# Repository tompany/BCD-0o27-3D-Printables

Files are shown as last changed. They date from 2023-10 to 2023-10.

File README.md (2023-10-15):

# BCD-0o27-3D-Printables

3D printable enclosure for the BCD-0o27-3 created by Florian Schuetz. The original project can be found here: https://gitlab.com/fschuetz/bcd-0o27

This is a 3D printable vintage Nintendo like casing for the BCD-0o27 including a print and assemble guide. Made this for two colleagues who visited the BalCCon2k23.

## What is in this repository
* The STL printable files are in the ["STL files"](./STL%20files) directory
* The **editable** original Autodesk Fusion 360 design is in the ["F3D files"](./F3D%20files) directory
* A print and assembly manual can be found here: [3D print and Assembly Manual](/3D%20print%20and%20Assembly%20Manual%20.md)

The design in the above-mentioned F3D file was created by Tom van Thiel, with the exception of the printed circuit board and the parts placed on it. That was copied from the original [BCD-0o27 repo](https://gitlab.com/fschuetz/bcd-0o27/-/tree/main/hardware/BCD-0o27?ref_type=heads) of [Florian Schuetz](https://gitlab.com/fschuetz).

If you have any question about the design, please send me a message on Discord: 703155474991939584 (display name: "Tompany")
P.s.: You can lookup Discord ID's here: [discord.id](https://discord.id/)

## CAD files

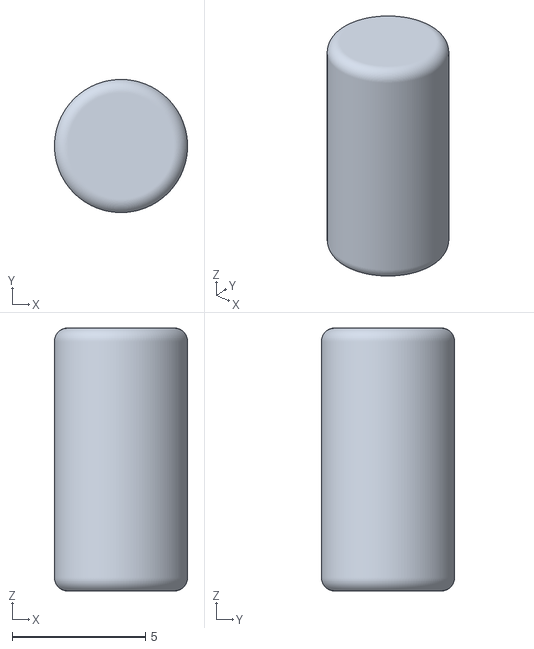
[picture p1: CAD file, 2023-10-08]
STL files/ANYCOLUR___bmRedButtonRodY.stl
5.00 x 5.00 x 9.88

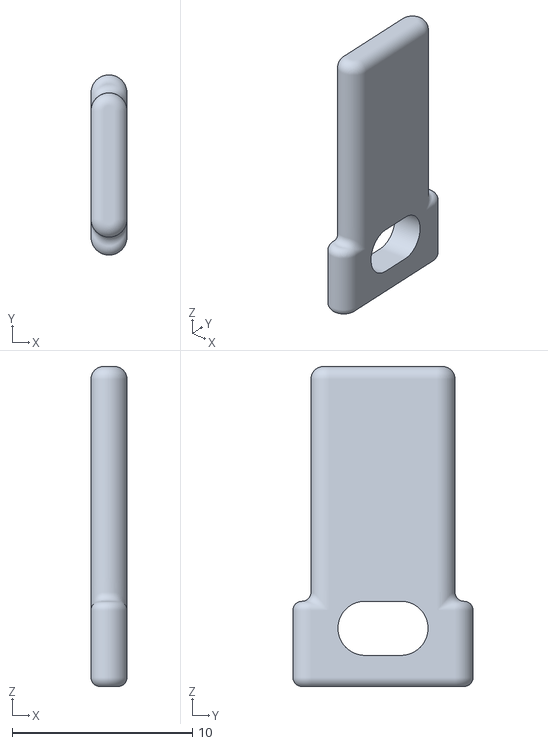
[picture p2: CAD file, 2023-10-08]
STL files/RED___bmRedButtonW.stl
2.00 x 10.00 x 17.8

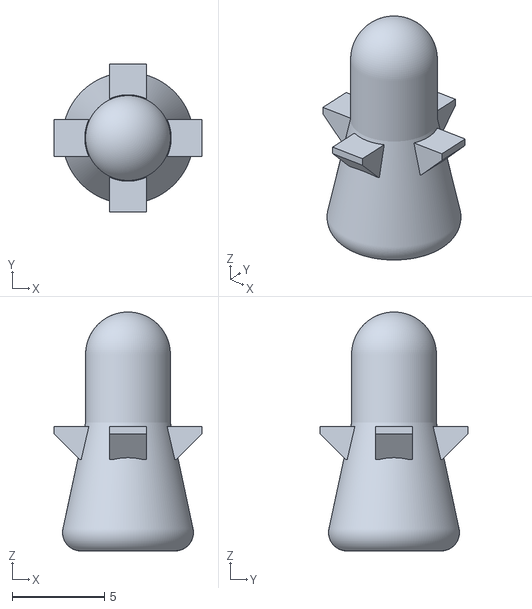
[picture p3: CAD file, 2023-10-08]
STL files/TRANSLUCENT___ldLEDCovr03.stl
8.00 x 8.00 x 13.0

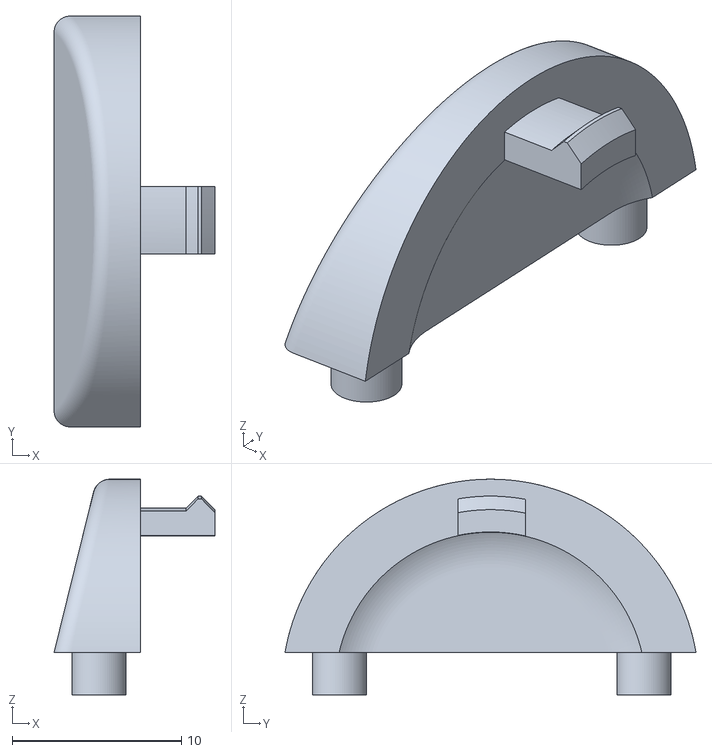
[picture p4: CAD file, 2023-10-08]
STL files/WHITE___bcCoverBatEnd.stl
9.51 x 24.3 x 12.7

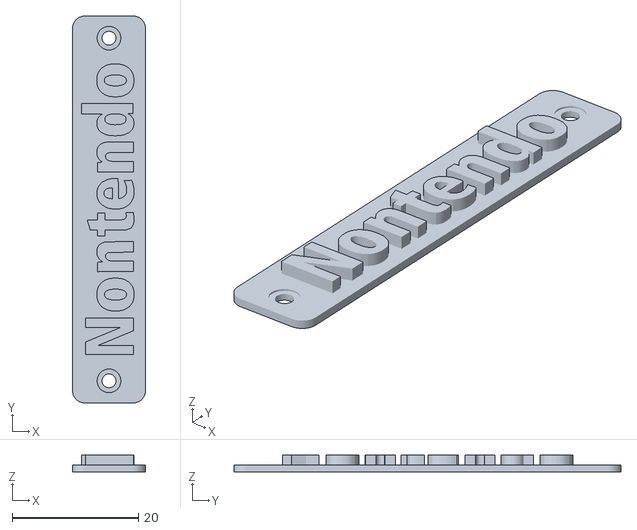
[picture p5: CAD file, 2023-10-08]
STL files/RED___ltNonTendo.stl
11.6 x 61.3 x 2.65

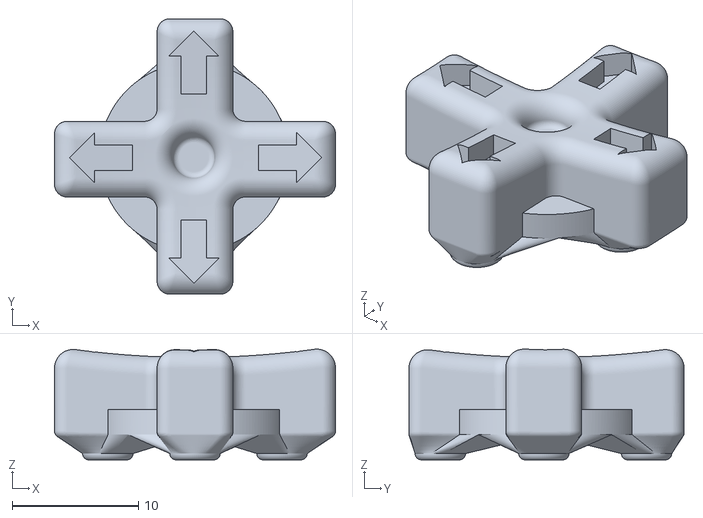
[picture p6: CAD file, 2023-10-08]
STL files/RED___bmXButton.stl
22.3 x 21.8 x 8.78

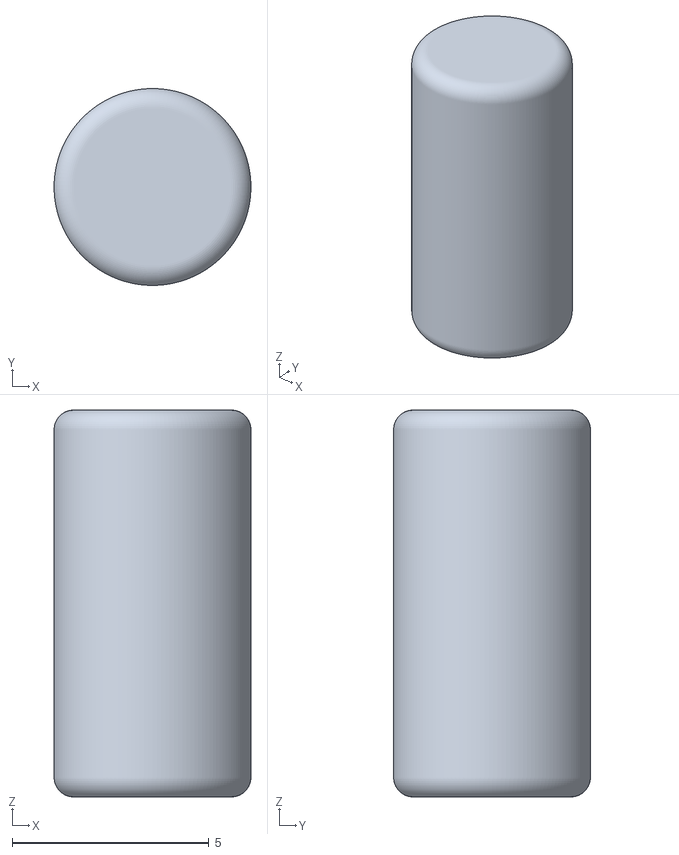
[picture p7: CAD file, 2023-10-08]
STL files/ANYCOLUR___bmXButtonRodS.stl
5.00 x 5.00 x 9.83

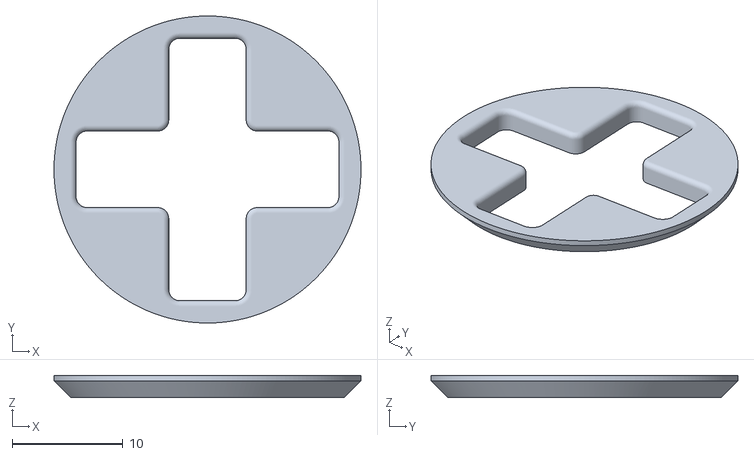
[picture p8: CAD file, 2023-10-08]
STL files/WHITE___acWhiteCirclesXbutton.stl
27.8 x 27.8 x 2.00

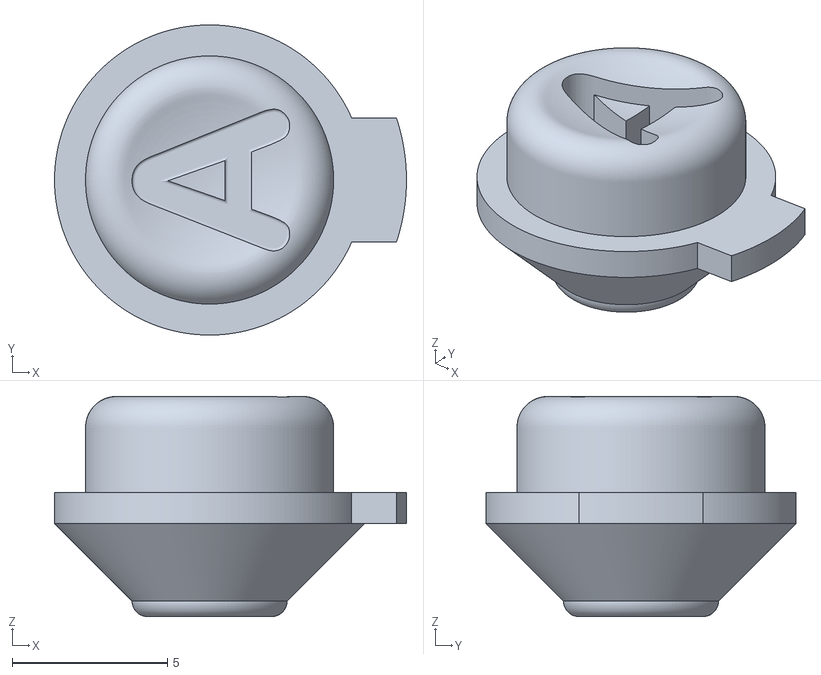
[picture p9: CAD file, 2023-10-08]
STL files/RED___bmRedButtonA.stl
11.3 x 10.00 x 7.10

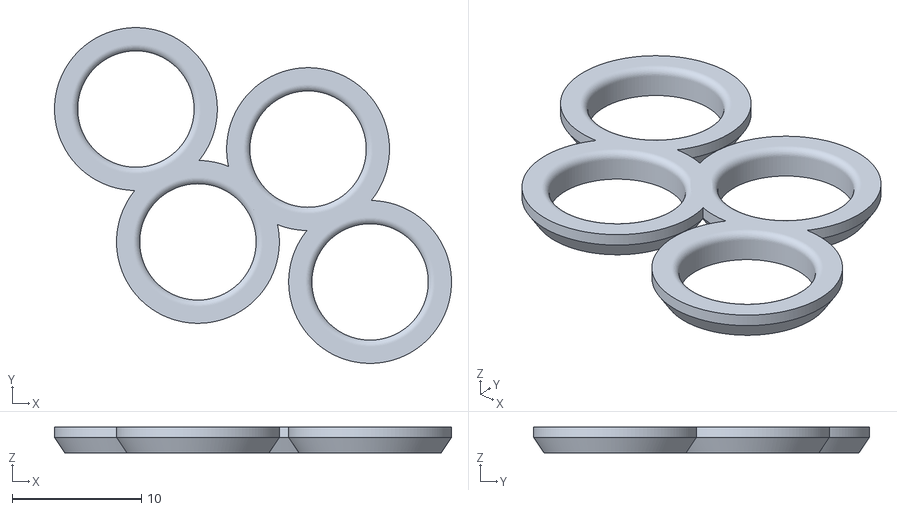
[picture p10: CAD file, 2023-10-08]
STL files/WHITE___acWhiteCirclesRedButtons.stl
30.7 x 26.0 x 2.00

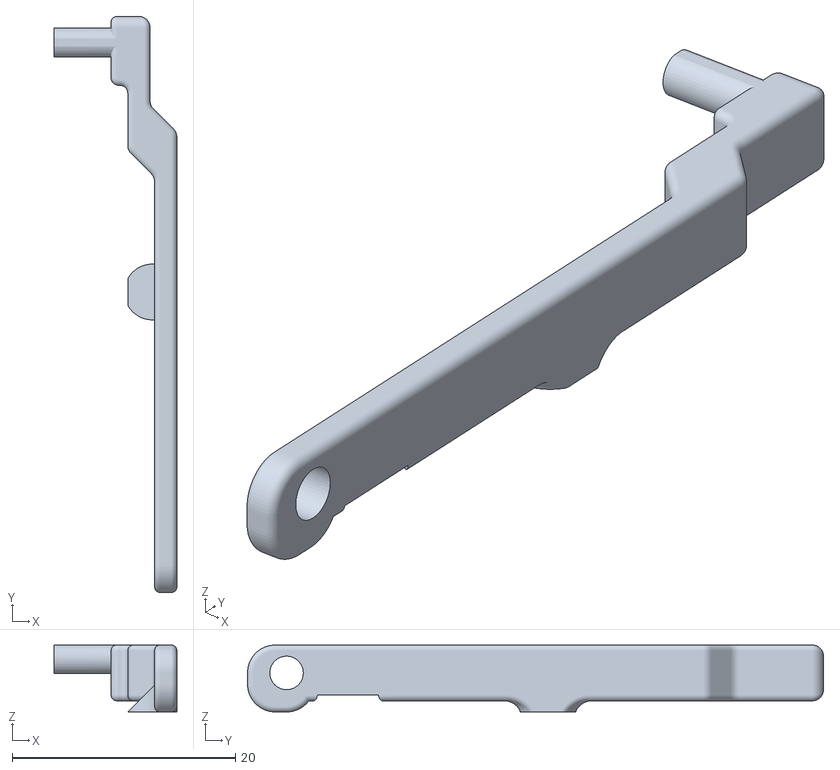
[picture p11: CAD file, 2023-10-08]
STL files/BLACK___bmBlackButtonLeverE.stl
11.0 x 51.6 x 6.00

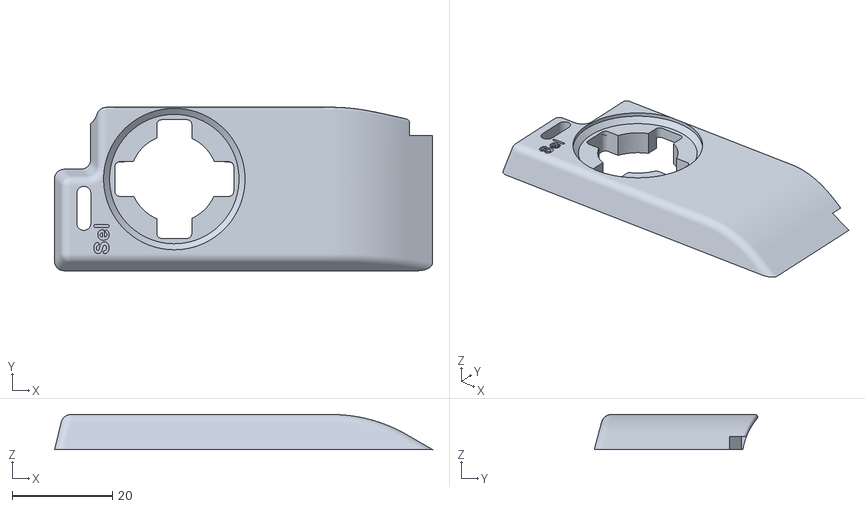
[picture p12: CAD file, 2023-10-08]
STL files/BLACK___bcSwitchCoverLeft.stl
75.6 x 32.7 x 7.00

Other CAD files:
STL files/ANYCOLUR___bmRedButtonRodX.stl
STL files/RED___bmRedButtonE.stl
STL files/ANYCOLUR___bmRedButtonRodA.stl
STL files/ANYCOLUR___bmXButtonRodNE.stl
STL files/ANYCOLUR___bmXButtonRodN.stl
STL files/ANYCOLUR___bmXButtonRodNW.stl
STL files/ANYCOLUR___bcPositionBlockLeft.stl
STL files/ANYCOLUR___bcPositionBlockRight.stl
STL files/ANYCOLUR___bmRedButtonRodB.stl
STL files/BLACK___bcSwitchCoverRight.stl
STL files/BLACK___bmBlackButtonLeverW.stl
STL files/BLACK___bmOnOffButton.stl
STL files/BLUE_TRANSP___bcCoverBot.stl
STL files/RED___bmRedButtonB.stl
STL files/RED___bmRedButtonX.stl
STL files/RED___bmRedButtonY.stl
STL files/TRANSLUCENT___ldLEDCovr01.stl
STL files/TRANSLUCENT___ldLEDCovr02.stl
STL files/TRANSLUCENT___ldLEDCovr04.stl
STL files/TRANSLUCENT___ldLEDCovr05.stl
STL files/TRANSLUCENT___ldLEDCovr06.stl
STL files/WHITE___bcCoverTop (FDM).stl

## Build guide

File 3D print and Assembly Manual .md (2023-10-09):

# 3D printable vintage case for the BCD-0o27

With a nod to an ancient Nintendo ;-)

| Front view | Back view | Front detail |
|:---:|:---:|:---:|
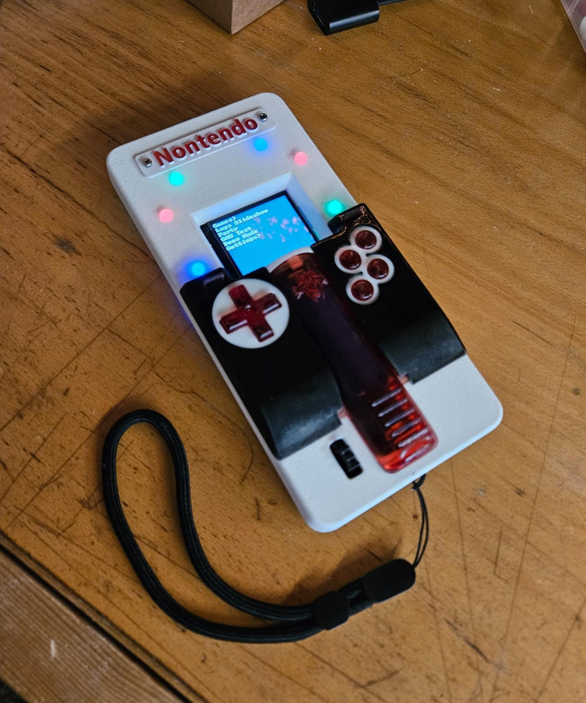
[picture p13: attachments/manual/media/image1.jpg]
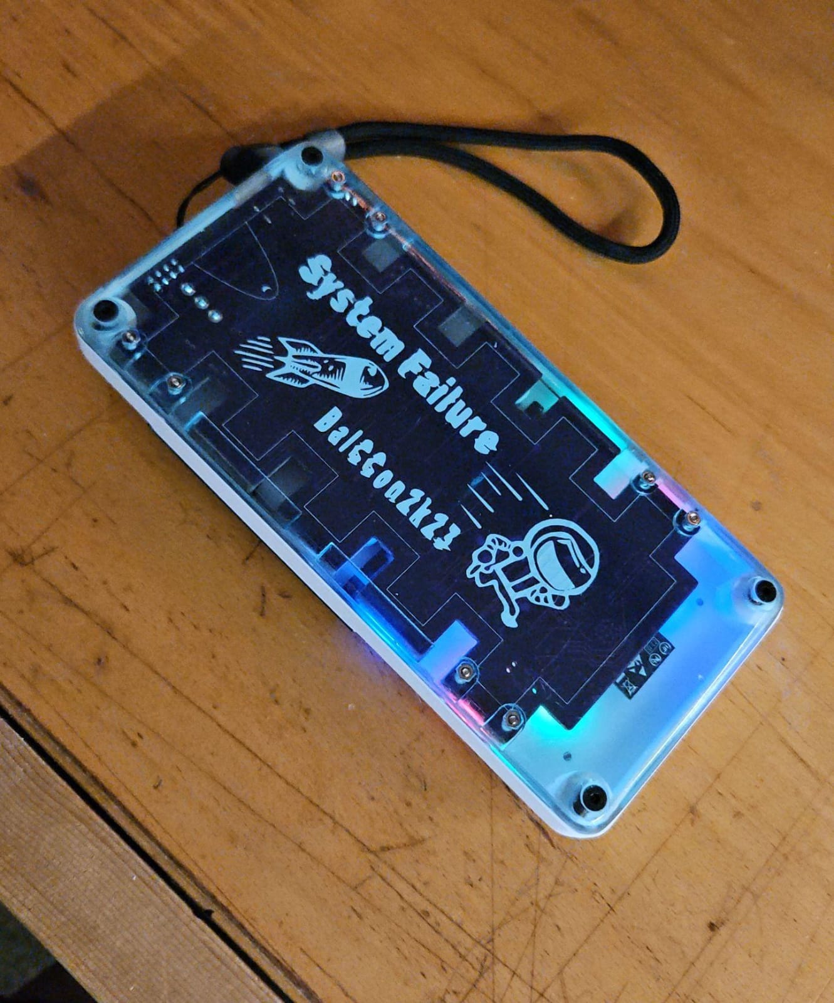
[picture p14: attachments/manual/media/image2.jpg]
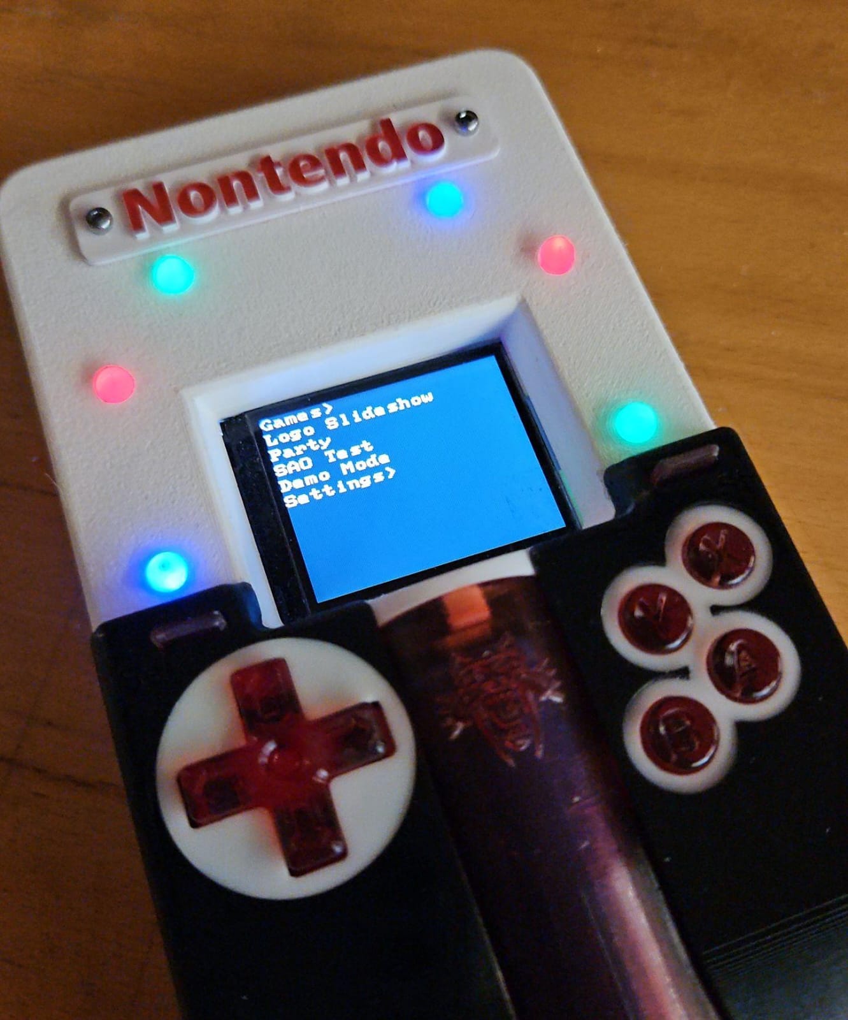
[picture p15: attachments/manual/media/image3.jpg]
|  |  | |

The BCD-0o27 is shaped in such a way that it lilits the creation of a real Nintendo 'look'. I tried to stay as close to the vintage Nintendo style as possible given the design of the PCB and it's components. I also gave it a transparent back so you can still see and show the BalCCon2k23 logo and 'Syetem Failure' sub-header on the back of the PCB. I hope you epreciate this design and have fun building / using it.

Contents

[1 Materials used for printing and constructing](#materials-used-for-printing-and-constructing)

[1.1 Resins used (SLA Printer: Anycubic Photon Mono X 6K)](#resins-used-sla-printer-anycubic-photon-mono-x-6k)

[1.2 Finishing of transparent components](#finishing-of-transparent-components)

[1.3 Required mounting materials such as heat inserts, nuts and bolts.](#required-mounting-materials-such-as-heat-inserts-nuts-and-bolts.)

[2 Exploded view](#exploded-view)

[3 Building instructions](#building-instructions)

[4 Tip: Two ways of making a two colour ‘Nontendo’ logo](#tip-two-ways-of-making-a-two-colour-nontendo-logo)

[5 Nintendo style hand bracelet](#nintendo-style-hand-bracelet)

#  

# Materials used for printing and constructing

Filaments used (FDM Printer: Voron 2.4-350)

-   Top Cover: Amazon Basics PLA White (need to print in PLA because
    threaded heat inserts are used).

Used a resin printer for all other parts to get maximum print quality.

## Resins used (SLA Printer: Anycubic Photon Mono X 6K)

-   Black parts:

    -   Elegoo Water Washable Photopolymer Resin, 1/1 mixture of Black
        and Smokey Black (The mixture produces better and stronger
        results than the components alone).

-   Red parts:

    -   Elegoo Water Washable Photopolymer Resin, Red.

-   White parts (except top cover)

    -   Elegoo Water Washable Photopolymer Resin, White

-   Blue parts (only bottom cover)

    -   Elegoo Water Washable Photopolymer Resin, Red

## Finishing of transparent components

The transparent components (red and blue) are sanded, polished and
lacquered to give the appearance of being made of glass.

## Required mounting materials such as heat inserts, nuts and bolts.

-   4x – M3 heat inserts

-   4x – M3x10mm zinc plated steel Hex Drive Flat Head Screw

-   10x – M2x7mm zinc plated steel socket head screw

-   8x – M2 zinc plated steel hex nut

# Exploded view

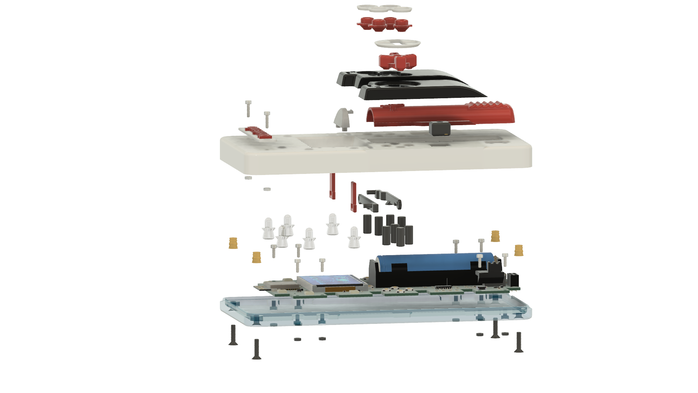
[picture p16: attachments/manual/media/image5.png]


# Building instructions

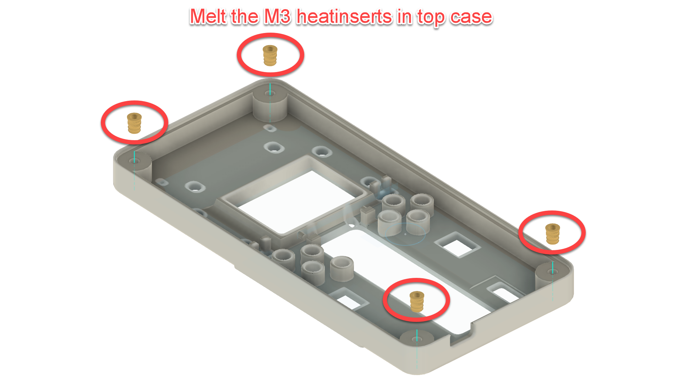
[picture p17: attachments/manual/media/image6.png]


-----

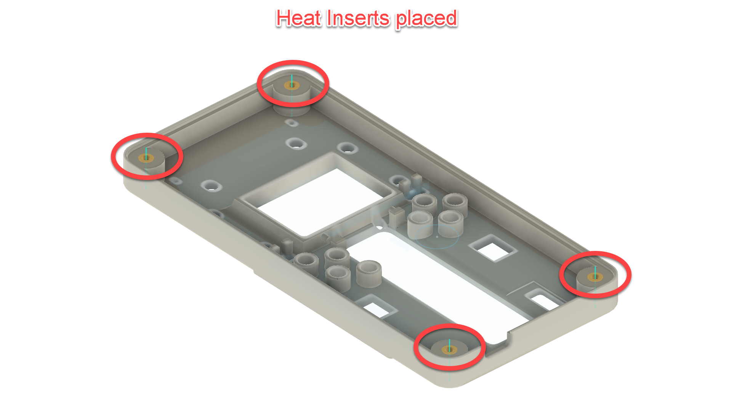
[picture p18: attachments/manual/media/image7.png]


-----

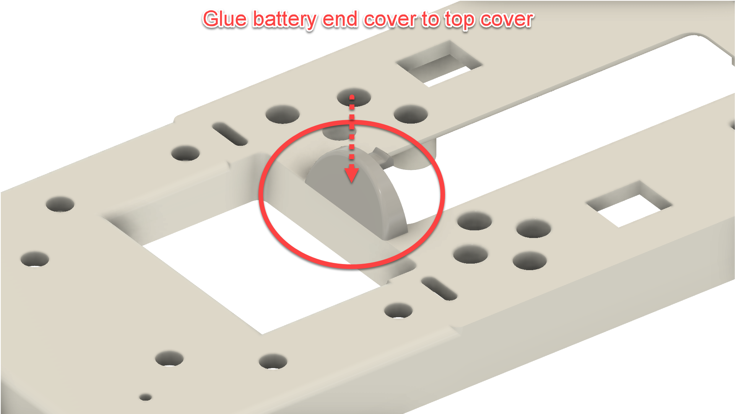
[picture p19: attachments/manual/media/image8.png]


-----

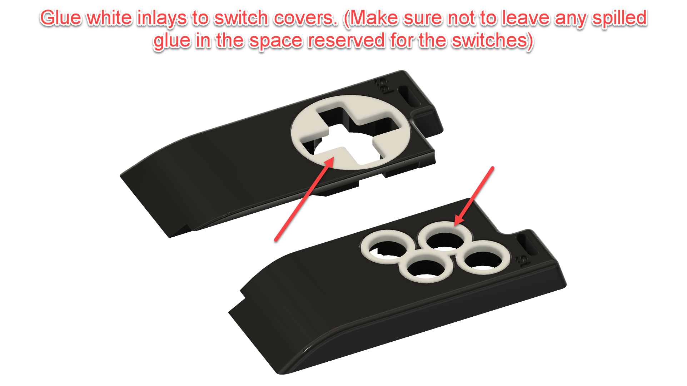
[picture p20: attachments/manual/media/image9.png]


-----

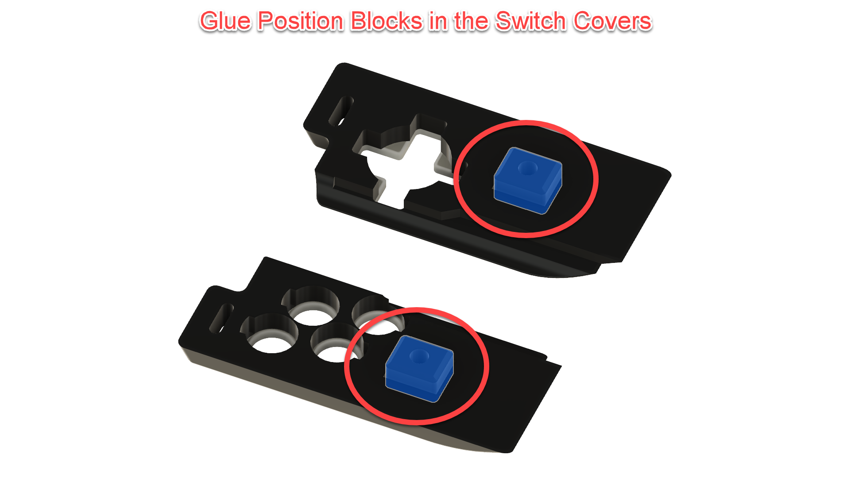
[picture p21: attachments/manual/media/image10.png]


-----

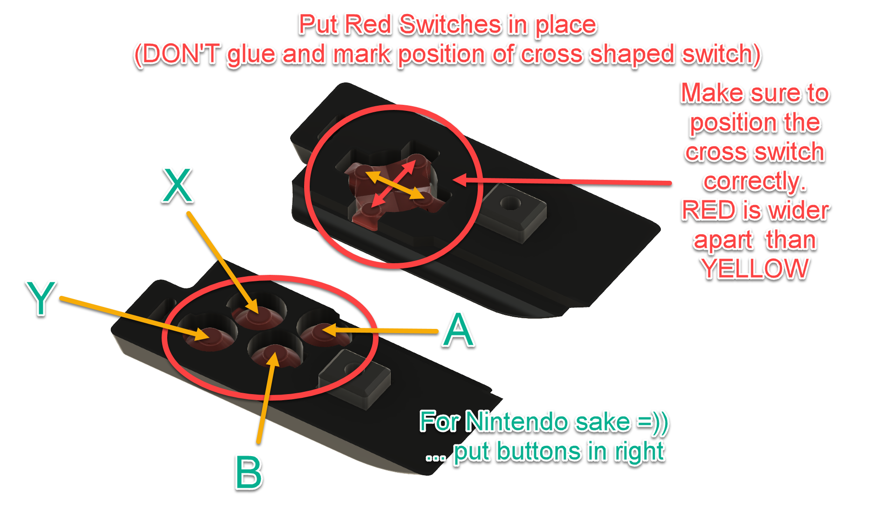
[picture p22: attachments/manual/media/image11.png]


-----

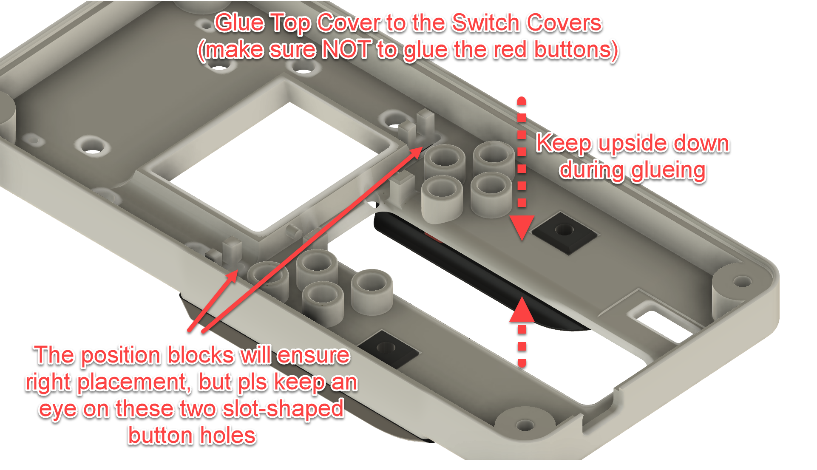
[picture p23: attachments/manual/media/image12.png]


-----

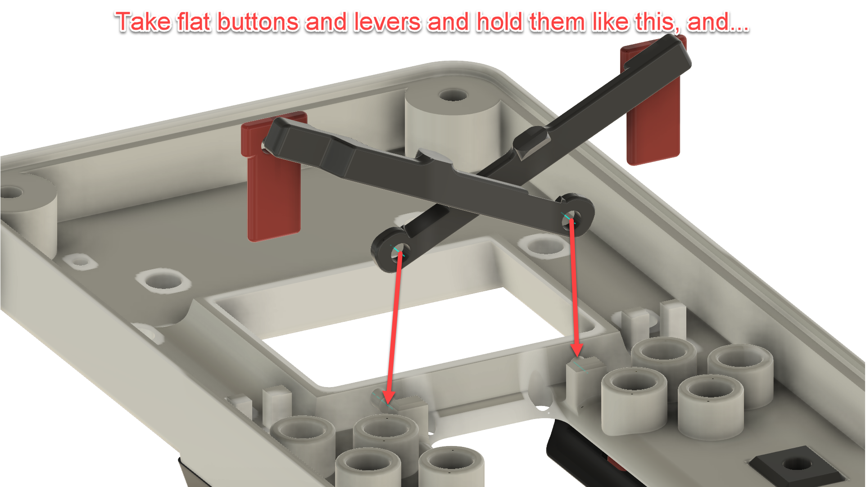
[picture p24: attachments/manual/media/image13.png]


-----

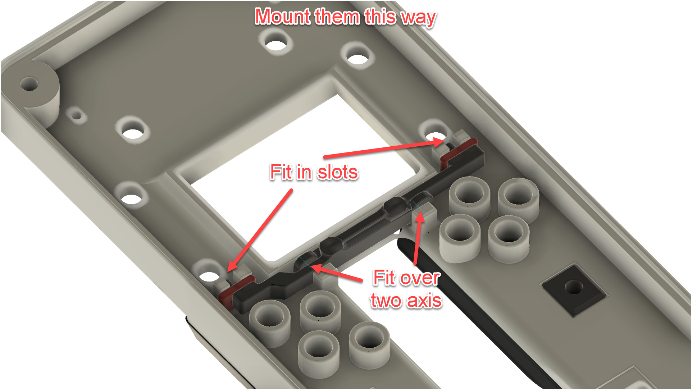
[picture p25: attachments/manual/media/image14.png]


-----

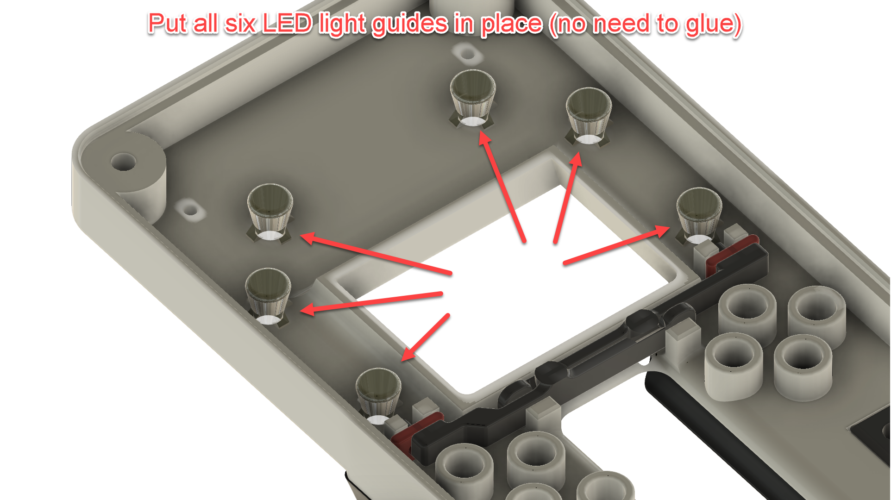
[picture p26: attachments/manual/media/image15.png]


-----

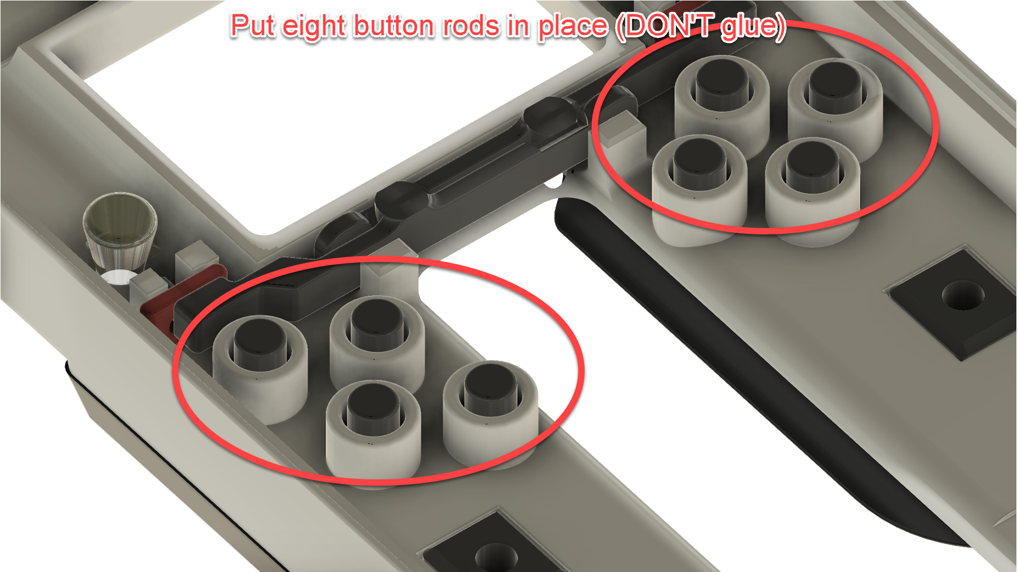
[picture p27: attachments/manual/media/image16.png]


-----

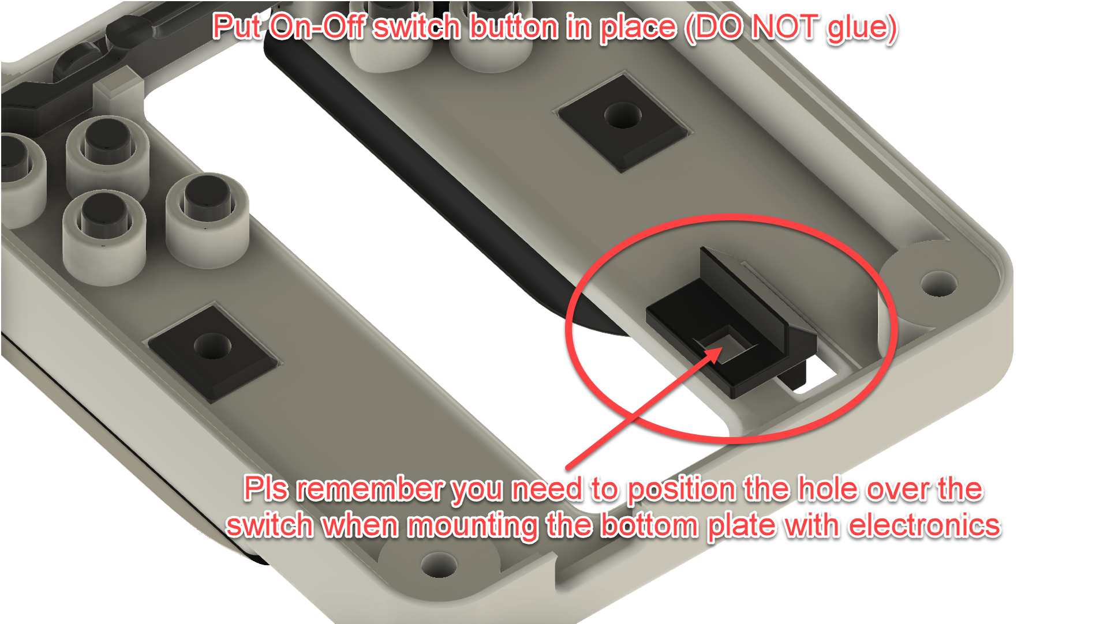
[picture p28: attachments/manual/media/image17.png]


-----

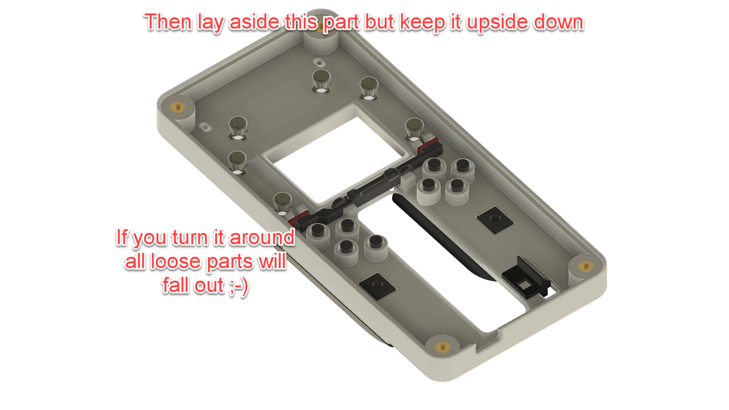
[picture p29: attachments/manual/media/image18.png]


-----

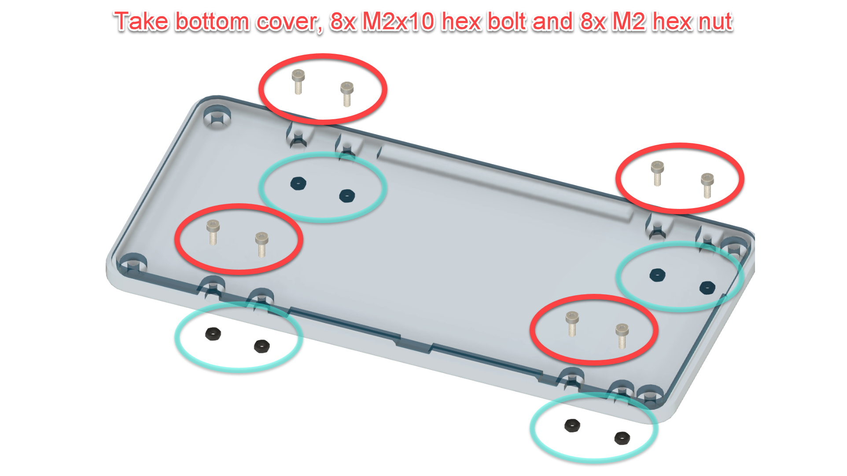
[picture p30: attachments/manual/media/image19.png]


-----

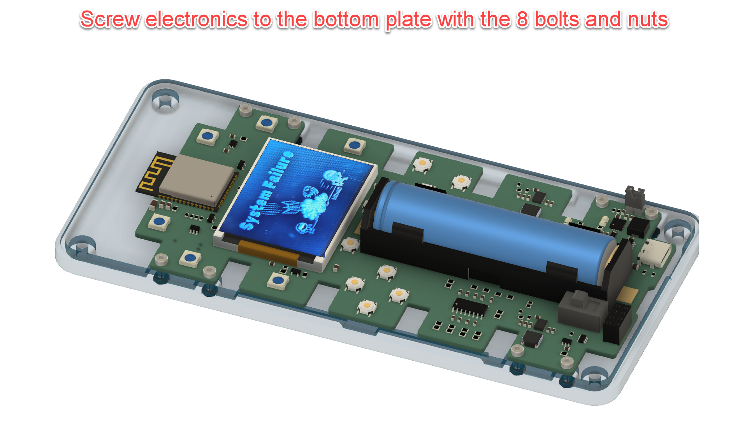
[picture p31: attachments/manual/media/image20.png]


-----

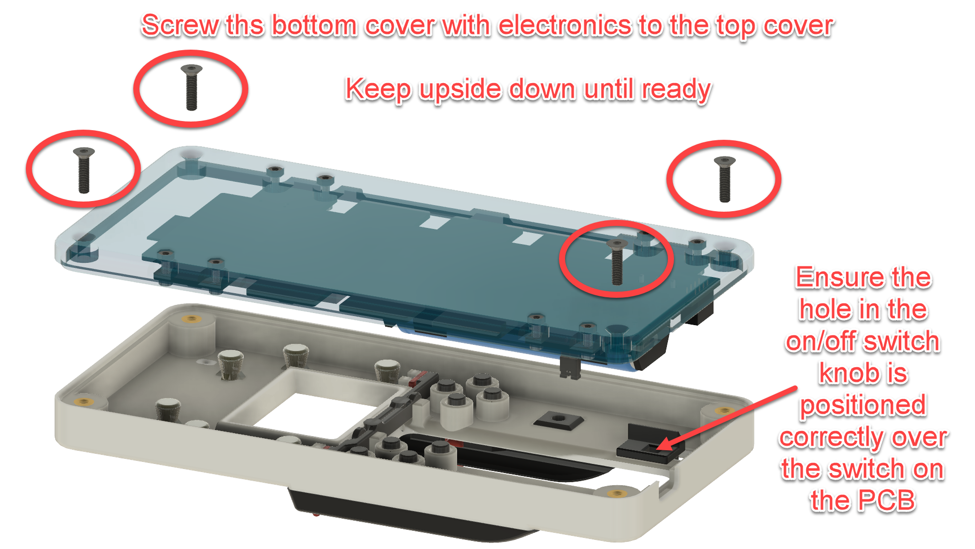
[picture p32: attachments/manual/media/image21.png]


-----

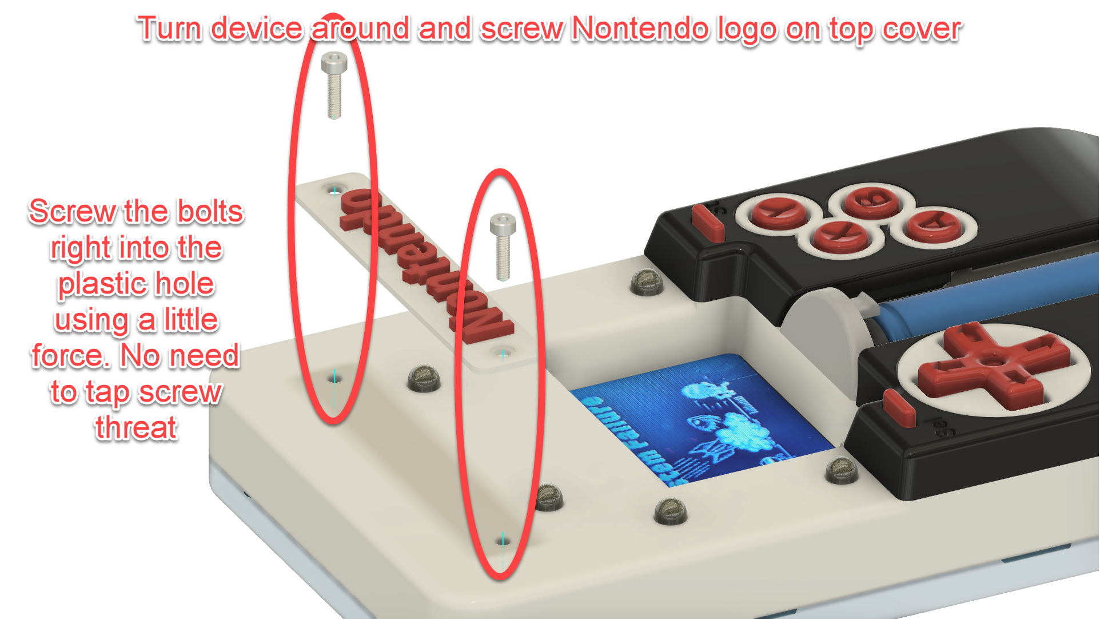
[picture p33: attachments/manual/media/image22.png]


-----

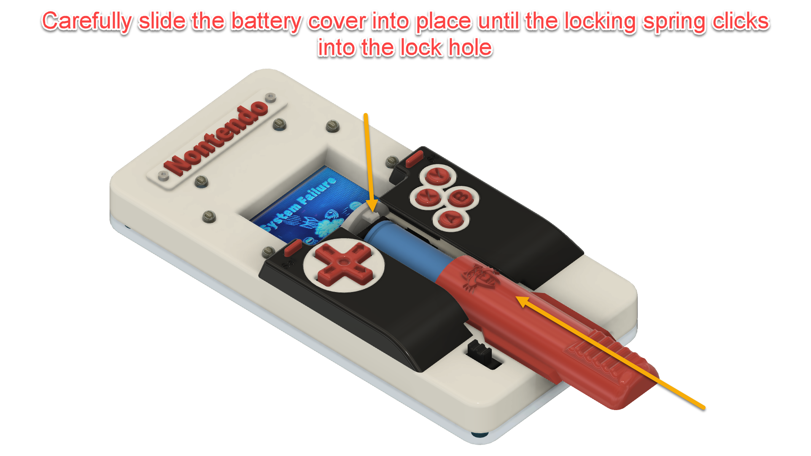
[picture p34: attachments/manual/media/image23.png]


-----

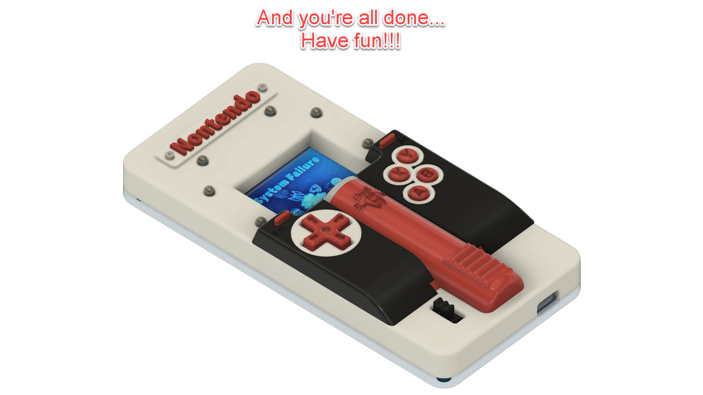
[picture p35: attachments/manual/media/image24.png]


-----

# Tip: Two ways of making a two colour ‘Nontendo’ logo

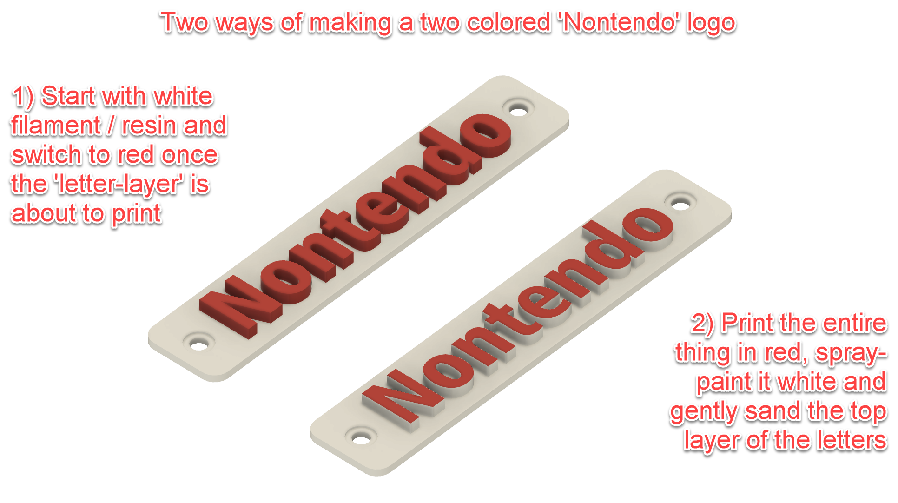
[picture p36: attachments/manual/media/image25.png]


-----

# Nintendo style hand bracelet

If you like the hand bracelet, you can order it here:

<https://www.amazon.nl/dp/B09PG46FR1?psc=1&ref=ppx_yo2ov_dt_b_product_details&language=en_GB>

There are no holes for the hand bracelet in the original design. You
will have to drill them, yourselves.



Have FUN…!!!

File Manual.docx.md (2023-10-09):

With a nod to an ancient Nintendo ;-)







Contents

[1 Materials used for printing and constructing](#materials-used-for-printing-and-constructing)

[1.1 Resins used (SLA Printer: Anycubic Photon Mono X 6K)](#resins-used-sla-printer-anycubic-photon-mono-x-6k)

[1.2 Finishing of transparent components](#finishing-of-transparent-components)

[1.3 Required mounting materials such as heat inserts, nuts and bolts.](#required-mounting-materials-such-as-heat-inserts-nuts-and-bolts.)

[2 Exploded view](#exploded-view)

[3 Building instructions](#building-instructions)

[4 Tip: Two ways of making a two colour ‘Nontendo’ logo](#tip-two-ways-of-making-a-two-colour-nontendo-logo)

[5 Nintendo style hand bracelet](#nintendo-style-hand-bracelet)

#  

# Materials used for printing and constructing

Filaments used (FDM Printer: Voron 2.4-350)

-   Top Cover: Amazon Basics PLA White (need to print in PLA because
    threaded heat inserts are used).

Used a resin printer for all other parts to get maximum print quality.

## Resins used (SLA Printer: Anycubic Photon Mono X 6K)

-   Black parts:

    -   Elegoo Water Washable Photopolymer Resin, 1/1 mixture of Black
        and Smokey Black (The mixture produces better and stronger
        results than the components alone).

-   Red parts:

    -   Elegoo Water Washable Photopolymer Resin, Red.

-   White parts (except top cover)

    -   Elegoo Water Washable Photopolymer Resin, White

-   Blue parts (only bottom cover)

    -   Elegoo Water Washable Photopolymer Resin, Red

## Finishing of transparent components

The transparent components (red and blue) are sanded, polished and
lacquered to give the appearance of being made of glass.

## Required mounting materials such as heat inserts, nuts and bolts.

-   4x – M3 heat inserts

-   4x – M3x10mm zinc plated steel Hex Drive Flat Head Screw

-   10x – M2x7mm zinc plated steel socket head screw

-   8x – M2 zinc plated steel hex nut

# Exploded view



# Building instructions







































# Tip: Two ways of making a two colour ‘Nontendo’ logo



# Nintendo style hand bracelet

If you like the hand bracelet, you can order it here:

<https://www.amazon.nl/dp/B09PG46FR1?psc=1&ref=ppx_yo2ov_dt_b_product_details&language=en_GB>

There are no holes for the hand bracelet in the original design. You
will have to drill them, yourselves.



Have FUN…!!!

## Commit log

2023-10-08 First version 3D printable BCD-0o27-3 enclosure
    This is the first version of the BCD-0o27-3 enclosure. The enclosure has a vintage Nintendo style and is tested on 2 PCD's to fit and work correctly.
    [ANYCOLUR___bcPositionBlockLeft.stl, ANYCOLUR___bcPositionBlockRight.stl, ANYCOLUR___bmRedButtonRodA.stl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]
2023-10-08 Pictures for the assembly manual in the WIKI
    Please see the WIKI for a complete 3D printing and assembly manual
2023-10-09 Rename Manual.md to 3D print and Assembly Manual .md
2023-10-09 Update 3D print and Assembly Manual .md
